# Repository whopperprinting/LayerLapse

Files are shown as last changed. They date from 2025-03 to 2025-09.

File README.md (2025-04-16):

# LayerLapse – 3D Printing Timelapse Trigger Device

art_layerlapse-editedv3

### What is LayerLapse?

**LayerLapse** is a camera trigger designed specifically for 3D printing. It captures a photo on every new layer using a hall effect sensor (magnet sensor) and a small magnet mounted to your print head — producing buttery-smooth, layer-by-layer timelapse footage. Perfect for makers, designers, content creators, or people who just want to see their prints from a new perspective.

The official LayerLapse device is a plug-and-play solution using a compact custom PCB designed, hand-built, and sold by me, **Whopper Printing**!  
You can get the completed, plug-and-play:  
  
👉 [LayerLapse kit here.](https://whopperprinting.com/products/layerlapse)
  
📷 [Timelapse taken with LayerLapse](https://www.instagram.com/reel/DH1gV0cPf0_/?igsh=cndwNTk0eG1vcTkw)

### Plug & Play

The LayerLapse system is completely independent electronically from your printer; nothing actually plugs into the printer. It requires no printer firmware modifications, soldering, or programming, nor does it make physical contact with any moving parts — meaning no unnecessary wear and tear on your printer (like a physical contact limit switch would cause.) You simply add a few lines of gcode in your slicer, and LayerLapse simply listens for the magnet and triggers your camera accordingly. A built-in dial lets you adjust the delay between magnet detection and photo capture (0–3 seconds, alterable), allowing your printer time to settle and eliminating blur caused by vibrations or motion that would otherwise show up on the final timelapse.

### Works With Any Printer

LayerLapse is completely printer-agnostic — from an Ender 3 to an X1C! You're not locked down to an ecosystem!
It works with virtually any 3D printer as long as you can mount the sensor somewhere near the toolhead and add a simple line of G-code in your slicer. I've included a [STEP file of the sensor board](docs/HallSensorTest.step) so you can fit test it on your setup to ensure it works for you before purchasing. Just print it out to test! I'm also including the STEP files so you can create your own enclosures and mounting brackets for any printer that you may have. (Coming soon)

### Camera Compatibility

**The [camera compatibility list](docs/camera_compatibility.md) is a work in progress.** I am still gathering more information. However, LayerLapse does come with a spare GPIO pin, so if you did happen to have issues, you could theoretically make it work with some creativity.

For example, the GPIO pin can control a bluetooth remote for mobile phones! Tutorial coming soon.

### Each LayerLapse kit includes:

- The compact, fully assembled LayerLapse mainboard
- A dedicated magnetic Hall effect sensor board
- 1 foot long, 3.5mm male-to-male sensor cable (3 foot long cable available as an add-on)
- A small 5×5×2mm neodymium magnet for mounting to your print head (can use your own)

### Not Included (can be added soon):
- The board is powered via USB-C (cable **not** included by default — available as an add-on soon)
- Camera shutter cables (2.5mm to your camera brand) are also **not** included by default, but will be available as optional add-ons soon

### Modifying the Board:

LayerLapse ships pre-programmed and ready to use, but if you'd like to upload custom firmware, you absolutely can! The board includes a 4-pin header for easy programming — three pins for flashing (VCC, GND, UPDI) and one extra GPIO pin for custom expansion. **You will need a UPDI programmer.**

The extra GPIO pin opens the door for creative mods: add a servo, LED, infrared module, or anything else you'd like to trigger on each layer change, provided your add-on is able to be adequately powered by 5V. For example, you could attach a servo to physically press a remote shutter — making LayerLapse compatible with virtually any camera system, even those without a shutter jack. [See pinout documentation.](docs/pinout.md)

> #### **Note:** You'll need a UPDI programmer (3-pin: GND, VCC, UPDI) to upload custom firmware.

---

## 🛠️ Getting Started (Quick Setup)

1. Plug in the components:
   - Connect the 3.5mm cable between the mainboard and the sensor board
   - Plug in a USB-C power cable
   - Connect the 2.5mm shutter cable from the mainboard to your camera
2. Mount the magnet to your 3D printer's toolhead (use the included 5×5×2mm magnet or use your own.)
3. Place the sensor near the printer’s parked position (that you choose in gcode) — ideally within ~10mm of the magnet at its closest pass so the sensor can pickup the magnet.
4. Duplicate your existing printer profile so you don't mess up your regular prints. This way, with the click of a button, you can change your printer from regular mode to timelapse mode and back.
5. Add G-code (like a custom layer change script) in your slicer to move the print head to that sensor location (e.g., G1 X0 Y200) after each layer. [Custom gcode available here.](code/custom-gcode)

Once set up, LayerLapse will automatically trigger your camera after every layer, creating smooth and consistent timelapse footage!

Go to the [Quick Setup page](docs/quick-setup.md) for detailed instructions on setup.

### ✨ Tips:

- Set a delay that is reasonable. If you take a photo right after triggering, you'll get vibrations in your timelapse.
- Make sure to set your focus wisely before starting. I recommend placing an object where you're going to print and focus on that. You don't want to look at your timelapse in the end and see it's out of focus.
- Make sure your camera's standby time is high enough to not cause lag during the capture. I had my camera set to go into standby mode after a few seconds. This caused a lag between the trigger and the camera actually taking the photo, ruining timelapses until I figured out the issue. But again, every camera is different, so test out your own settings before committing to a print.
- Use an AC dummy battery for your camera. You wouldn't want your camera dying halfway through a print.

---

## 🧩 Custom Mounts/Enclosures

[3D Files](docs/3D-files)
  
I am working on making custom brackets to easily attach the sensors to my printers. My hope is that others will post their mounts as well for their own setups and printers. I am also working on an enclosure for the LayerLapse device, but I will also be uploading the final STEP file for the board so anyone can design their own enclosure!

---

## 🔧 Uploading Firmware (Only needed if you're customizing — LayerLapse is shipped preloaded and ready to use from the box)

Steps:
1. Copy the [code from here](code/DIY_LayerLapse_firmware.txt) for a starting point
2. Paste it into the Arduino IDE
3. Connect your UPDI programmer to the board (3-pin: GND, VCC, UPDI)
4. Select the correct board/port and upload

---

## 🧠 Want to Build Your Own?

For those who prefer to build their own timelapse device, I have written a [full DIY guide](docs/diy-build-guide.md). While the DIY route is completely possible using off-the-shelf components, **LayerLapse was created to save time, simplify the process, and deliver beautiful results right out of the box.** No soldering, wiring, or programming.

---

## 🤝 Contributing

Want to improve the firmware, add camera compatibility info, or help make this project better?
Please read the [contributing guidelines](CONTRIBUTING.md) before submitting a pull request or opening an issue.

---

## 🛡️ License

The code in this repo is licensed under the **MIT License** — for firmware only.  

> 🛠️ You are welcome to build your own DIY version using Arduino components and the open firmware provided.🚫 However, the PCB and branding are not licensed for reproduction or resale.

[Click to view full license](LICENSE)

---

## 💬 Support & Contact

Created by **Whopper Printing**  

Support me [on Patreon!](https://www.patreon.com/whopperprinting)

For questions, feedback, or orders:  
📩 Email: whopperprinting@gmail.com  
🔗 Website: [whopperprinting.com](https://whopperprinting.com/) <- Purchase LayerLapse here!  

### Socials

📷 Instagram: [@whopperprinting](https://instagram.com/whopperprinting)  
🕒 TikTok: [@whopperprinting](https://www.tiktok.com/@whopperprinting?is_from_webapp=1&sender_device=pc)

**LayerLapse™ and Whopper Printing™ are trademarks of Whopper Printing. All rights reserved.**

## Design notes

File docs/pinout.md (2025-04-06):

# 📌 LayerLapse Pinout (ATtiny1604)

This table outlines the key pin assignments for the LayerLapse device using the ATtiny1604 microcontroller.

| Function | ATtiny1604 Pin # | Name | Direction | Description |
|---|---|---|---|---|
| Shutter Trigger | 7 | PB2  | Output | Controls camera shutter via transistor (tip + ring) |
| LED Indicator | 6 | PB3  | Output | Status LED for visual feedback |
| Hall Effect Sensor | 9 | PB0  | Input | Detects magnet to trigger photo |
| Potentiometer Dial | 11 | PA1  | Input | Adjusts delay (0–5 seconds) |
| GPIO Expansion | 12 | PA2  | Output | Optional expansion (servo, IR, etc.) |
| UPDI Programming | 10 | PA0 (Reset/UPDI)  | I/O | Used for flashing firmware |
| GND | 14 | GND  | — | Ground |
| VCC | 1 | VDD  | — | 5V power input (via USB-C) |

## Pinout Diagram
  
If you are programming the board yourself with Arduino IDE, you will need to use the orange and blue boxes for the pin numbers.
  
ATtiny1604-pinout

[Full ATTiny1604 Datasheet](https://ww1.microchip.com/downloads/en/DeviceDoc/ATtiny804-06-07-1604-06-07-DataSheet-DS40002312A.pdf)

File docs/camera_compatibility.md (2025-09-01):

# Camera Compatibility

This is a list of cameras that have been tested and confirmed to work with LayerLapse via a 2.5mm shutter release cable. This list is a work in progress. Hit Ctrl + F on your keyboard to find your camera.

**Mobile phones can be triggered with LayerLapse using the onboard GPIO pin, but you'll need to do some hacking. You'll have to wire the GPIO pin to a bluetooth shutter for phones, for more advanced users. Tutorial coming soon.**

If I receive enough requests for a specific camera to be made compatible, I will consider making a special PCB to make it work for that camera.

✅ = Fully working  
⚠️ = Should work/unverified  
❌ = Not compatible

---

## ✅ Confirmed Working (Click to open each category)

<details>
<summary><strong>Nikon (N3 - MC-DC2)</strong></summary>

- Z7 / Z7 II / Z6 / Z6 II / Z6 III / Z5
- D750 / D780 / P1000 / D7500 / D7200 / D5600 / D5500 / D5300 / D5200 / D5100 / D5000 / D3300 / D3200 / D7000 / D7100 / D610 / D600
- D90
- Df
- Nikon Coolpix P7700 / Coolpix P7800 / Coolpix P1000 / Coolpix P1100

</details>

<details>
<summary><strong>Canon (C1/C2 - RS-80N3 & RS-60E3)</strong></summary>

- T3i(600D)

</details>

## ⚠️ Should Work (Unverified, need to confirm)

<details>
<summary><strong>Nikon (N1 - MC-30)</strong></summary>
  
- Nikon Z9 / Z8
- Nikon D850 / D810 / D800 / D700 / D500
- Nikon D1 / D1h / D1x / D2H / D2x / D2Xs / D3 / D3s / D3x / D4 / D4s / D5 / D100 / D200 / D300 / D300s
- Nikon F5 / F6 / F90 / F90x / F100

</details>

<details>
<summary><strong>Olympus (C1)</strong></summary>
</br>
  
CB1 Connector:

- OM-1, E-M1X, E-M1 Mark II, E‑M1 Mark III, E-M5 Mark III

</details>

<details>
<summary><strong>Samsung (C1)</strong></summary>
  
- GX-1L, GX-1S, GX-10, GX-20, NX100, NX11, NX10, NX5

</details>

<details>
<summary><strong>Canon (C1/C2 - RS-80N3 & RS-60E3)</strong></summary>
  
- EOS R1 / R3 / R5 / R5 Mark II
- EOS 1D / 1D C / 1Ds / 1D Mark II / 1D Mark II N / 1D Mark III / 1D Mark IV / 1D X Mark III / 1D X Mark II / 1Ds Mark II / 1Ds Mark III 
- EOS 5D / 5DS / 5DS R / 5D Mark II / 5D Mark III / 5D Mark IV / 6D / 6D Mark II / 7D / 7D Mark II
- EOS 10D / 20D / 20Da / 30D / 40D / 50D / EOS 1V / EOS 3 / D30 / D60 / D2000
- Rebel XS(1000D) / T3(1100D) / T5(1200D) / T6(1300D) / T7(1500D) / SL1(100D) / SL2(200D) / SL3(250D) / XT(350D) / XTi(400D) / XSi(450D) / T1i(500D) / T2i(550D) / T4i(650D) / T5i(700D) / T6i(750D) / T6s(760D) / T7i(800D) / T8i(850D)
- EOS 60D / 60Da / 70D / 77D / 80D / 90D / R / RP / R6 / R6 Mark II / R7 / R8 / R10 / R100 / M6 / M6 Mark II / M5 
- Powershot G10 / G11 / G12 / G15 / G16 / G1X / G1X Mark II / G1X Mark III / G3X / G5X / SX50 HS / SX60 HS / SX70 HS

</details>

<details>
<summary><strong>Pentax (C1 - RS-60E3)</strong></summary>
  
- K1 / K3 / K3 II / K5 / K5 II / K5 IIs / K7 / K30 / K50 / K10D / K20D / K100D / K100D Super / K110D / K200D / K500 / 645D / 645Z / ist / ist D / ist DL / ist DL2 / ist Ds / ist DS2 / MZ-6 / MZ-L / ZX-L

</details>

<details>
  
<summary><strong>Sony (S2)</strong></summary>
  
- Sony Alpha A58 / A3000 / A3500 / A5000 / A5100 / A6000 / A6100 / A6300 / A6400 / A6500 / A6600
- Sony Alpha A1 / A1 II / A9 / A9 II / A9 III / A7 / A7 II / A7 III / A7 IV / A7R / A7R II / A7R III / A7R IV / A7R V / A7S / A7S II / A7S III / NEX-3NL
- Sony DSC-HX300 / HX400 / HX400V / HX50V / HX60V / HX90 / HX90V
- Sony DSC-RX10 / RX10 II / RX10 III / RX10 IV / RX100 II / RX100 III / RX100 IV / RX100 V / RX100 VI / RX100 VII / RX1R II / WX500 / ZV-1
- Sony ILCE-a1, a9, a9M2, a7, a7M2, a7M3, a7M4, a7R, a7RM2, a7RM3, a7RM4, a7S, a7SM2, a7SM3, a6600, a6100, a6400, a6500, a6300, a6000, a5000, a5100, a3000, a3500
- QX1
- HX300, HX350, HX400, HX400V, HX50, HX50V, HX60, HX60V, HX99, HX95, HX90, HX90V, HX80
- QX30
- RX0, RXOM2, RX100M2, RX100M3, RX100M4, RX100M5, RX100M5A, RX100M6, RX100M7, RX10, RX10M2, RX10M3, RX10M4, RX1RM2
- WX500, WX700, WX800
- a58, a68
- NEX-3N
- ZV-1

</details>

<details>

<summary><strong>Fujifilm (F3 - RR-100)</strong></summary>

</br>
Works with Fujifilm cameras that have a 2.5mm socket:
</br>
</br>

- Fujifilm X-T5 / X-T4 / X-T3 / X-T2 / X-T1 / X-T30 II / X-T30 / X-T20 / X-T10 / X-T100 / X-H1 / X-H2 / X-H2S / X-A5
- Fujifilm GFX100SII / GFX 100S / GFX 100 / GFX 50R / GFX 50S / GFX 50S II
- Fujifilm X100VI / X100V / X100F / X100T / X70 / X30 / XF10
- Fujifilm X-E3 / X-E2S / X-E2 / X-E1
- Fujifilm X-PRO3 / X-PRO2
- FinePix S5 Pro, S3 Pro

</details>

<details>
  
<summary><strong>Panasonic (DMW-RSL1)</strong></summary>
  
- DC-S1 / DC-S1R / DC-S1H / DC-S5 / DC-G9 / G9 II / DC-GH7 / DC-GH6 / DC-GH5 / DC-GH5S / DC-FZ2500 / DC-FZ2000 / DC-FZ1000 / DC-FZ1000 II
- DMC-G1 / DMC-G10 / DMC-G2 / DMC-G3 / DMC-G5 / DMC-G6 / DMC-G7 / DMC-G85 / DMC-GF1 / DMC-GH1 / DMC-GH2 / DMC-GH3 / DMC-GH4 / DMC-GX7 / DMC-GX8 / L1 / L-10 / LC-1 / DMC-FZ300 / DMC-FZ100 / DMC-FZ150 / DMC-FZ20 / DMC-FZ200 / DMC-FZ20K / DMC-FZ20S / DMC-FZ30 / DMC-FZ30K / DMC-FZ30S / DMC-FZ50 / DMC-FZ50K / DMC-FZ50S
- Lumix S9 Cameras
- G100D Cameras

</details>

<details>
  
<summary><strong>Contax (C1)</strong></summary>
  
- 645, N1, NX, N Digital

</details>

<details>
  
<summary><strong>Sigma (C1)</strong></summary>
  
- Sd1

</details>

---

## ❌ Not Compatible
- Sony A7C/ A7C II / A7CR cameras
- Nikon D3500 / D3400 / Z50 / Z fc
- Fujifilm X-M5 / X-T50 / GFX100 II
- [Gathering more info]

---

Want to contribute your results? Open an issue or email [whopperprinting@email.com](mailto:whopperprinting@email.com)!

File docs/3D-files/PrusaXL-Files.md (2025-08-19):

# Agepbiz's LayerLapse Files

The talented Agepbiz was kind enough to share his files with the community. He made a suite of 3D files that can be downloaded to make the LayerLapse fully plug/play and compatible with the PrusaXL. He also shared custom gcode for other PrusaXL users.
  
Find the files and information on [his Printable's account.](https://www.printables.com/model/1389278-smooth-timelapse-on-the-prusa-xl-layerlapse)

Be sure to also [checkout his other content!](https://www.youtube.com/redirect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)

imgi_1_layerlapse_prusa_xl_01

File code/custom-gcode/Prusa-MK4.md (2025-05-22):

This is code that was sent to me by a LayerLapse user.

This parks the printer on the left side between layers. I don't personally have this printer, so please use discretion.

Here's what it looks like in the PrucaSlicer under "Printers" "custom G-code" and "After_Layer_Change"

;Move printer head to far left corner for picture  
G0 X0 Y500  
;pause for picture  
G4 S1

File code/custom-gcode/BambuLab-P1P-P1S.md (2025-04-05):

# For BambuLab P1P and P1S (presumably X1 printers also)

Copy and paste the code below into "Layer change G-code" in the printer settings in the BambuStudio slicer.

You are welcome to change the **G4 P900** to any other value you'd like. The 900 is 900 milliseconds. If you modify this, make sure you modify the code on LayerLapse to ensure they work in harmony.

```
; layer num/total_layer_count: {layer_num+1}/[total_layer_count]
M622.1 S1 ; for prev firware, default turned on
M1002 judge_flag timelapse_record_flag
M622 J1
{if timelapse_type == 0} ; timelapse without wipe tower
M971 S11 C10 O0
;
{elsif timelapse_type == 1} ; timelapse with wipe tower
G92 E0
G1 E-[retraction_length] F1800
G17
G2 Z{layer_z + 0.4} I0.86 J0.86 P1 F20000 ; spiral lift a little
G92 E0
G1 E-[retraction_length] F1800
G17
G2 Z{layer_z + 0.4} I0.86 J0.86 P1 F20000 ; spiral lift a little
G1 X256 Y200 F20000 ; THIS IS THE PARKED POSITION, change this if you want to change the parking position if you put the sensor in a different location (F20000 is the speed, this can be left the same)
G4 P900 ;wait 900 milliseconds before moving after parking (THIS IS THE DELAY TIME. This is how long the printer will stay parked in the positon while the camera takes a photo.)
{endif}
M623
; update layer progress
M73 L{layer_num+1}
M991 S0 P{layer_num} ;notify layer change
;
```
In your slicer printer settings, turn on "smooth" under timelapse. You can move the prime tower anywhere on the print plate that is best for you and your camera position.

smoothtimelapse

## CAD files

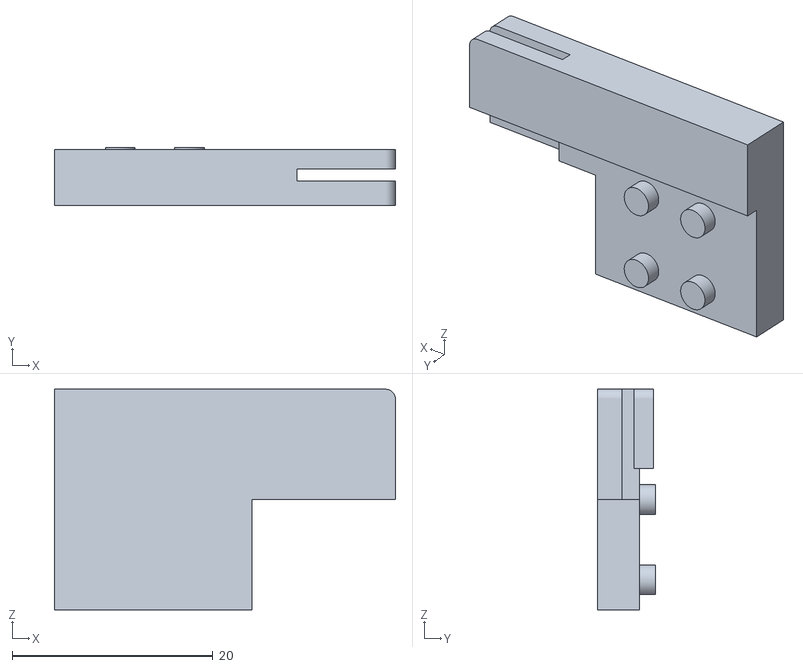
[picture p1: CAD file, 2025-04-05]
docs/3D-files/Brackets-Mounts/Bambu/HallSensorBracket-P1P.stl
34.0 x 5.80 x 22.0

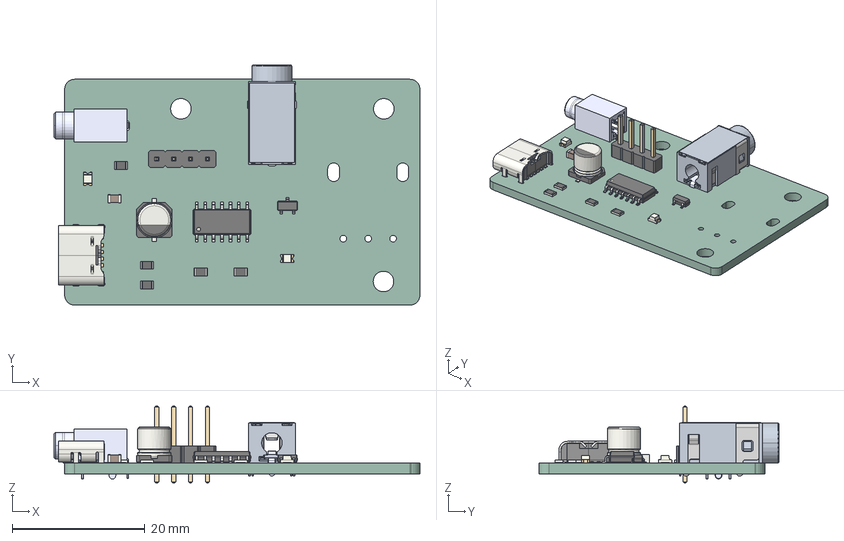
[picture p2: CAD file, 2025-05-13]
docs/3D-files/LayerLapse.step
55.1 x 36.2 x 11.5 mm
R_0805_2012Metric x 5
PinHeader_1x04_P254mm_Vertical
SOIC_14_39x87mm_P127mm
SOT_23
USB_C_Receptacle_GCT_USB4125-xx-x_6P_TopMnt_Horizontal
CP_Elec_5x54
Same_Sky_SJ1-2503A
LED_0805_2012Metric_Castellated x 2
C_0805_2012Metric
TimelapseDevice_PCB

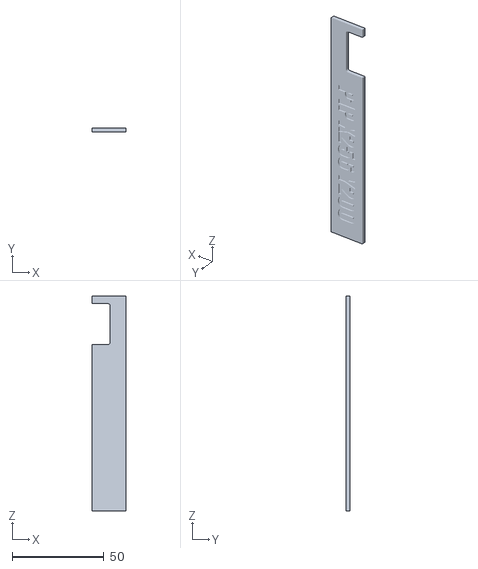
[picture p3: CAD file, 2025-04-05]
docs/3D-files/Brackets-Mounts/Bambu/SensorLocator.stl
18.7 x 1.97 x 117.1

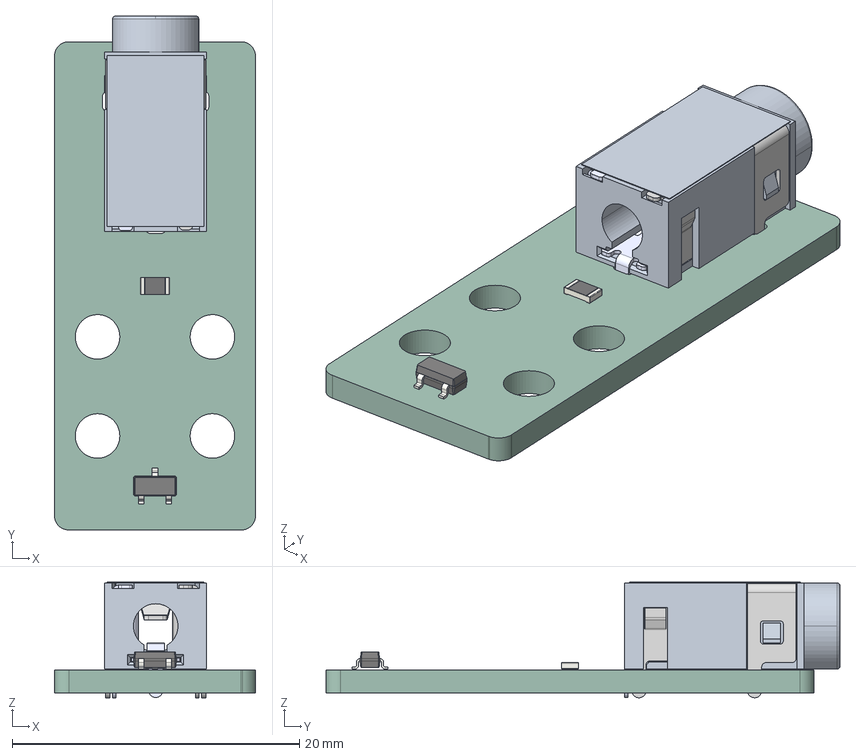
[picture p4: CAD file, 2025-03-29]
docs/3D-files/HallSensor-3Dmodel.step
14.0 x 35.8 x 8.05 mm
SOT_23
R_0805_2012Metric
HallSensor_PCB

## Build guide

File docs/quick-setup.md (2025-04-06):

## 🛠️ LayerLapse Setup

1. Plug in the components:
   - Connect the 3.5mm cable between the mainboard and the sensor board
   - Plug in a USB-C power cable
   - Connect the 2.5mm shutter cable from the LayerLapse mainboard to your camera
   
2. Mount the magnet to your 3D printer's toolhead (use the included 5×5×2mm magnet or use your own)
   - Note: I use tape, it's easy to remove if I ever need to and I've had no issues on any of my printers. It's also easy to reposition during setup.
   
4. Place the sensor near the printer’s parked position (that you choose in gcode) — ideally within ~10mm of the magnet at its closest pass so the sensor can pickup the magnet.
   - A blue LED lights up on the mainboard when a magnet is detected. This should help you find the sweet spot for where to park and mount your sensor. Just move your print head around until the LED lights up!
   
  
  
Use tape to mount the sensor, or design your own custom mount for your printer using the [STEP file](docs/HallSensorTest.step) of the sensor!
Check out the [existing brackets that have been designed](docs/3D-files/Brackets-Mounts). Feel free to make your own and add to this project!
  
6. Duplicate your existing printer profile so you don't mess up your regular prints. This way, with the click of a button, you can change your printer from regular mode to timelapse mode and back. Doing it this way also means you have clean gcode to default back to in case you make mistakes.
   
8. Add G-code (like a custom layer change script) in your slicer to move the print head to that sensor location (e.g., G1 X0 Y200) after each layer. [Custom gcode available here.](code/custom-gcode)
   - This step will be different for everyone depending on the printer and slicer you are using. Below is how to do it in Bambu Studio for Bambu printers, but the idea is the same for all printers and slicers. You also have the freedom to change the parked position and delay that will best suit your own needs.
  
---
## For P1/X1 Printers
1. Click the edit preset button in Bambu Studio.
   
sliceredit-bambu

---
  
2. Go to the Machine gcode tab. Scroll down to the Layer change G-code section, and copy/paste or modify [the Gcode for your printer.](code/custom-gcode)
   
  gcode2
  
Note: This is an example I made for the P1P, but if you decide to change the position of your magnet or sensor, you'll need to change the position in the gcode. To do that, modify this line in the gcode (the X and Y coordinates):
  
``
G1 X256 Y200 F20000 ; THIS IS THE PARKED POSITION, change this if you want to change the parking position if you put the sensor in a different location (F20000 is the speed, this can be left the same)
``

---
  
3. Save your new preset as a different name (i.e., P1P Timelapse), this way you can swap between timelapse mode and regular printing with the click of a button.
   
  save

Once set up, LayerLapse will automatically trigger your camera after every layer, creating smooth and consistent timelapse footage!

### Additional Info:

Here is a [custom mount I made for the Bambu P1P.](docs/3D-files/Brackets-Mounts/Bambu/HallSensorBracket-P1P.stl)
If you use this bracket and are using my code, I also [made a sensor locator](docs/3D-files/Brackets-Mounts/Bambu/SensorLocator.stl) so you can perfectly place the sensor where the code specifies.
  
Here is where to place the sensor locator in order to have an accurate location:

sensorlocator

---

### For A1 Mini

Follow the setup for the X1/P1 printers, but on step 2, instead of the Layer change section, use the Time lapse G-code section.
  
AImini

Then copy/paste the [A1 Mini specific gcode](code/custom-gcode) into this section.

  Notes:
    
  The parked position will be near the filament wiper on the end. You can change this position and delay by changing these lines in the code:

``
G1 X-1 Y180 F18000 ;THIS IS THE PARKED POSITION, CHANGE THE X AND Y VALUES TO CHANGE THE PARKED POSITION
M400 P300 ; THIS IS THE DELAY BETWEEN PARKING AND CONTIUING PRINTING, CHANGE THE P VALUE TO CHANGE THE DELAY (P300 is 300 miliseconds)
``

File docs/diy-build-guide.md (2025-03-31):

# DIY Build Guide

**Disclosure:** Some links below are Amazon affiliate links. As an Amazon Associate, I earn from qualifying purchases. Using these links helps support the project at no extra cost to you.

This guide will help you build your own basic version of the LayerLapse timelapse trigger using off-the-shelf parts. To get the plug & play LayerLapse, [visit my website!](https://whopperprinting.com/products/layerlapse)

## 🔌 What You Need

***Right click the links and click "open in new tab" to keep the instructions open.***

| Item | Example/Link |
|---|---|
| Microntroller (like an Arduino or anything else that you have) | [What I used](https://amzn.to/4ibiYyZ) |
| Hall effect sensor (3-pin, e.g., A3144) | [What I used](https://amzn.to/4ja3YCi) |
| Camera trigger (compatible with your camera) | [What I used](https://amzn.to/4hSzcg3) |
| Transistor (e.g., PN2222) | [What I used](https://amzn.to/3Y7ognG) |
| 1k Ohm resistor | [What I used](https://amzn.to/4hTAXtA) |
| Breadboard jumper wires | [What I used](https://amzn.to/3RqsenG) |
| Magnets | [What I used](https://amzn.to/4j6uLz9) |

You'll also need an AC power dummy battery (get one compatible with your camera). You'll need this for long printing sessions, so your camera doesn't die mid print.
This is [what I used](https://amzn.to/3XERjiq) for my Nikon camera.

### Optional:
| Item | Example/Link |
|---|---|
| Breadboard (optional) | [What I used](https://amzn.to/4292l0u) |
| 10k Ohm Potentiometer | [What I would use](https://amzn.to/4j2ZoFK) |
| 3M Double Sided Tape | [What I would use](https://amzn.to/4iLMnk6) |

# Steps

### Initial Setup
  
1. Take apart the camera trigger using a small screwdriver. The goal is to get the circuit boards by themselves. We just want the 2.5mm jack PCB from this trigger.

     Taking apart the camera trigger

2. We can set aside the button circuit board. We will only be using the 2.5mm female jack for this project. You can cut the wires between them or unsolder them.
3. Now we have all the parts we need for this project. Onto the wiring.

### Wiring

***Note: All the pin numbers are arbitrary, but if you just want to copy and paste the code later, use the same pins.***
  
1. Connect the positive pin of the Hall sensor to the 5V pin on your Arduino
2. Connect the GND pin of the Hall sensor to the GND on the Arduino
3. Connect the OUT pin of the Hall sensor to pin 7 of the Arduino
4. Connect the GND pin from the 2.5mm female jack PCB that we just isolated  **and** the AF pin to the ***emitter*** of the transistor
5. Connect a 1k Ohm resistor to a jumper wire, and connect this to pin 5 of the Arduino
6. Connect the RLS pin from the 2.5mm jack PCB **and** the GND from the Arduino to the ***collector*** pin

Your device should look like the wiring below:



### 📂 Code

You are now ready to upload the code to your Arduino.
  
[You can find the code to copy-paste here.](/code/DIY_LayerLapse_firmware.txt)

## Mounting Sensor & Magnet

Everyone has different printers so this step will look different for everyone, but the main idea is the same.

### Steps

1. Affix a magnet to your print head; somewhere the sensor will be able to get close to it. ***On my Bambu Lab P1P, I placed the magnet on the bottom of the print head near the back right corner and taped it.***
2. Attach the sensor to the printer, somewhere it will be safe during printing. It needs to be right next to the magnet at its parked location. ***On my P1P, I taped the sensor to the frame on the right side near the back***

  Sensor location

## Custom gcode

This is the very last step of the whole build. You'll need to figure out a location to park your printhead during the timelapse. For example, I parked my P1P in the back right corner, then I taped the hall sensor to the frame right under where the magnet will be parked during the photo capture. Save this location and add this to the layer change gcode in your slicer. This is the final puzzle piece to the whole system.

### Tip: Make sure that you duplicate your existing printer profile before making modifications. This will allow you to easily switch between regular printing mode and timelapse mode with the click of a button.

[See gcode examples here.](/code/custom-gcode)

## Final Remarks

Now all thats left is to plug in your Arduino, plug in your camera to the 2.5mm jack, and get to printing!

### Tips:

- Add a new printer profile in your slicer and name this "Timelapse" or something to that effect. That way you can still print normally, but when you want a timelapse, you can just switch printer profiles.
- Set a delay in your code that is reasonable. If you take a photo right after triggering, you'll get vibrations in your timelapse.
- Make sure to set your focus wisely before starting. I reccomend placing an object where you're going to print and focus on that. You don't want to look at your timelapse in the end and see it's out of focus.
- Make sure your camera's standby time is high enough to not cause lag during the printing. I had mine set to go into standby mode after a few seconds. This caused lag between the trigger and the camera actually taking the photo, ruining timelapses until I figured out the issue. But again, every camera is different, so test out your own settings before committing to a print.
- Use an AC dummy battery for your camera. You wouldn't want your camera dying halfway through a print.

---

## 🤝 Support Me!
This DIY guide is offered freely to everyone!

Consider supporting me [on Patreon!](https://www.patreon.com/whopperprinting)

If you'd like a compact, plug-and-play, pre-assembled version, [check out the official LayerLapse device](https://whopperprinting.com/products/layerlapse)! (Releasing April 2025)
